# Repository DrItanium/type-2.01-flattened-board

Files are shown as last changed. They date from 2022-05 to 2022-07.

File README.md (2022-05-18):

This project is a flattening of my i960 Eurocard Bus design into a mini itx
motherboard. The idea is that by leveraging the mini-itx/atx ecosystem I will
save a bunch of money. In this design, the chipset is an adafruit grand central
m4 with ram being provided by a file on an SD card (dedicated SD channel +
an effective cache implementation works wonders to hide nearly all latency).

The grand central m4 is exposed out the io shield area. You will see the
evolution of many ideas and where it started from as well. 

I have two 4809 microcontrollers on board as well. They are titled ME and PIC. 

ME or Management Engine abstracts the details of how one handles memory
transactions made by the i960. It generates the 20MHz clock and runs in lock
step with the i960Sx as well. The chipset (GCM4) interacts with the ME to
satisfy these requests. The communication protocol between chipset and ME is
designed to allow the chipset to run completely independently of the ME without
running too fast or out of sync. The ME also uses its CCLs to reduce the number
of ICs required. This includes:

- Enabling data lines on request by chipset
- Fail signal detection (externally synchronized)
- Ready signal detection with external override
- Controlling the i960 reset line (Chipset, ME, and PIC all have to be ready
		before i960 is pulled out of reset). Pullups and an external inverter
		are used to make sure that the i960 will stay in reset until everything is
		ready. 

PIC or Programmable Interrupt Controller makes sure that one can invoke any of
the four exposed interrupt lines by the i960Sx in a consistent manner. A serial
communication channel is provided to allow the chipset to configure the PIC.
The general idea is that each CCL of the PIC is devoted to a separate interrupt
line. The first three interrupts (~INT0, INT1, INT2) are meant for dedicated
interrupts within the i960. The third interrupt (~INT3) is the lowest priority
and designed for the chipset. When the chipset needs to interrupt the i960, it
sends an ~INT3. This causes the i960 to query the chipset what kind of
interrupt it was (through MMIO) and then send an IAC message to trigger an
internal interrupt. 

The PIC has peripherals like timers and such that can be connected to the CCLs
to trigger interrupts. The chipset talks with the PIC through the serial
connection to setup these options via the event system.

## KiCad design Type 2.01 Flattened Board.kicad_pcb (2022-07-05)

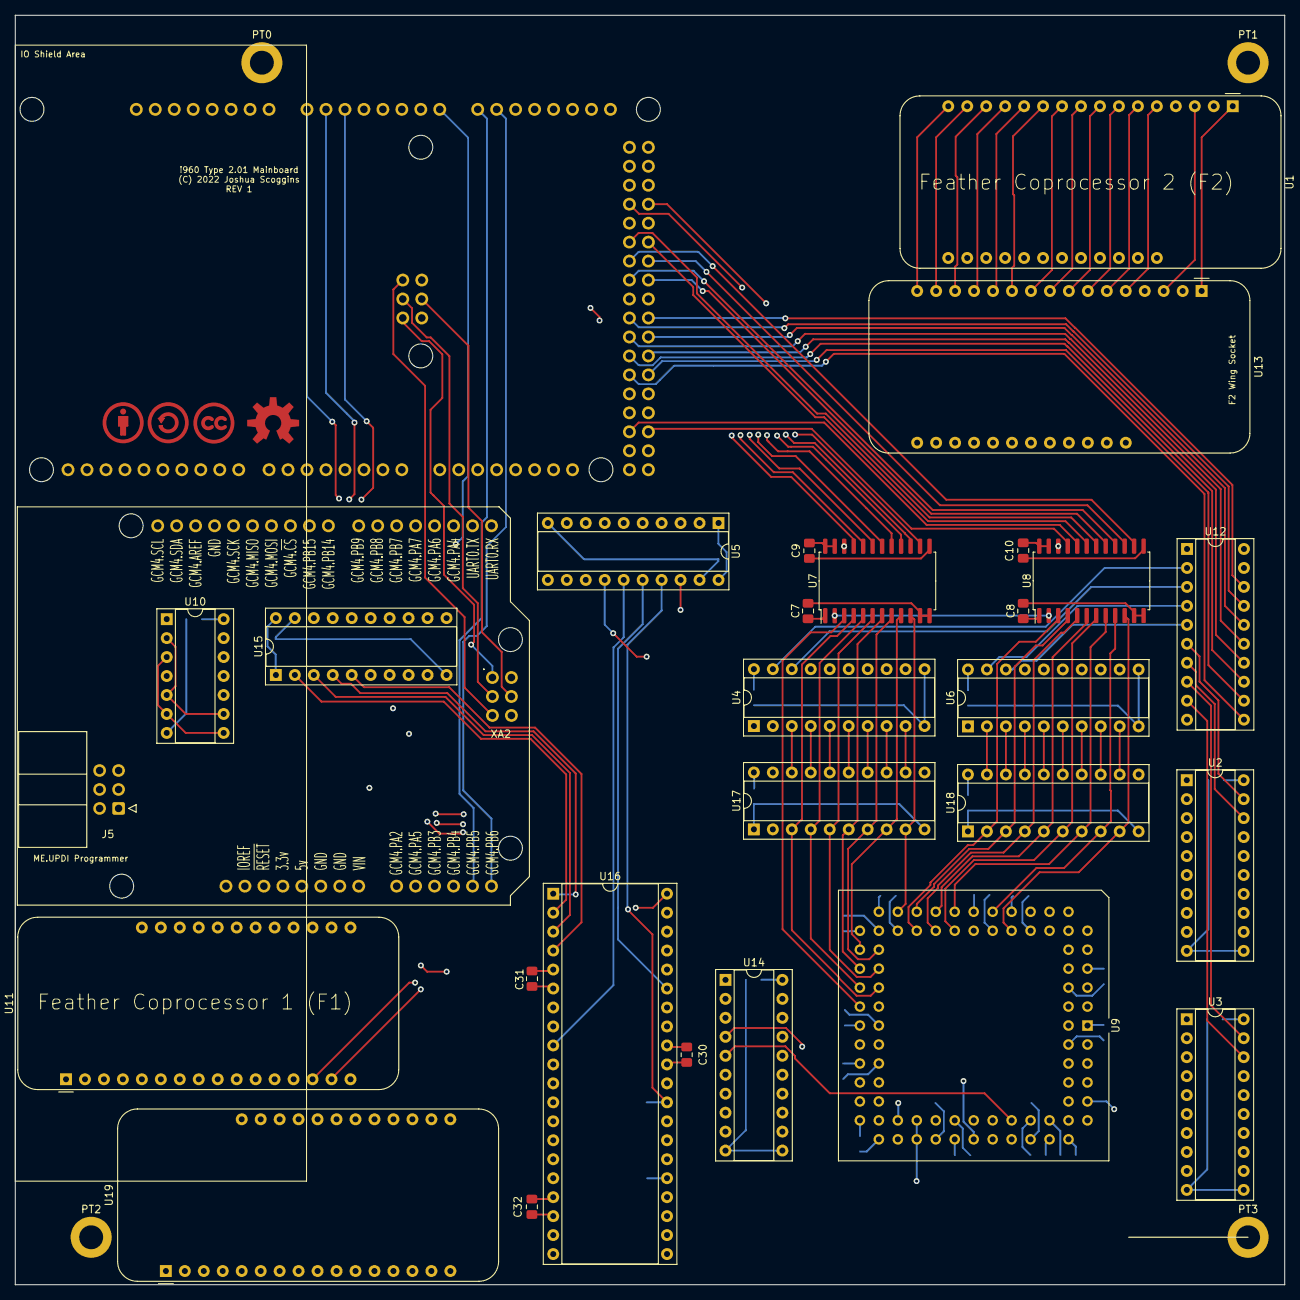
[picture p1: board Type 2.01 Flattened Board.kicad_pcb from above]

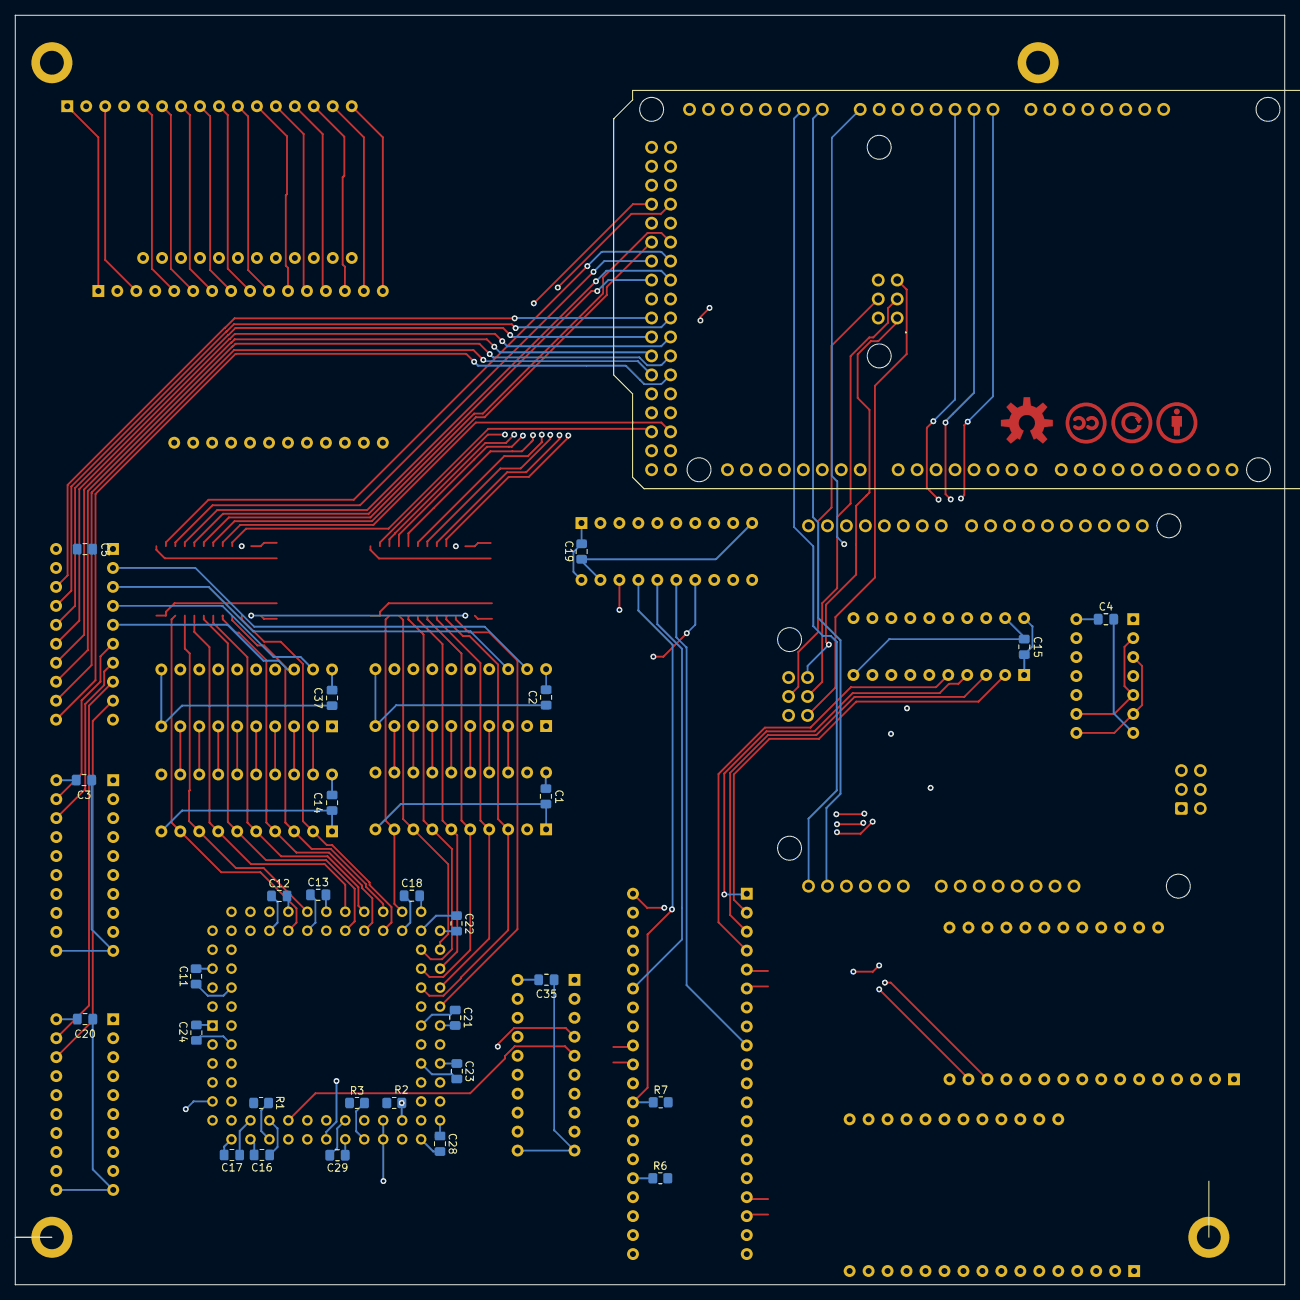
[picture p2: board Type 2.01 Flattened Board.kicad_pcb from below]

Board: 4 copper layers, 170.0 x 170.0 mm, 61 parts (29 on the bottom side), 209 nets.

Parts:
C1, C2, C3, C4, C5, C7, C8, C9, C10, C11, C12, C13, C14, C15, C16, C17, C18, C19, C20, C21, C22, C23, C24, C28, C29, C30, C31, C32, C35, C37: 0.1uF; C_0805_2012Metric_Pad1.18x1.45mm_HandSolder
J5: Conn_02x03_Odd_Even; IDC-Header_2x03_P2.54mm_Horizontal
PT0, PT1, PT2, PT3: MountingHole; MountingHole_3.2mm_M3_ISO14580_Pad
R1: 910; R_0805_2012Metric_Pad1.20x1.40mm_HandSolder
R2, R3, R6, R7: 10k; R_0805_2012Metric_Pad1.20x1.40mm_HandSolder
U1, U11, U13, U19: Adafruit_FeatherWing; Adafruit_Feather
U2, U3, U4, U6, U14: GAL16V8; DIP-20_W7.62mm_Socket
U5, U12, U15: 74AHC245; DIP-20_W7.62mm_Socket
U7, U8: 74LVC8T245; SOIC-24W_7.5x15.4mm_P1.27mm
U9: i960Sx_PLCC84; PLCC-84_THT-Socket
U10: 74AHC125; DIP-14_W7.62mm_Socket
U16: ATmega4809-PF; DIP-40_W15.24mm_Socket
U17, U18: 74AHC573; DIP-20_W7.62mm_Socket
XA1: Adafruit Grand Central M4; Arduino_Mega2560_Shield
XA2: Arduino_Uno_Shield

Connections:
+3.3V: U1.2 (3.3v), U1.28 (BAT), U11.2 (3.3v), U11.28 (BAT), U13.2 (3.3v), U13.28 (BAT), U19.2 (3.3v), U19.28 (BAT)
+3V3: XA1.3V3 (3.3V), XA2.3V3 (3.3V)
+5V: C1.1, C2.1, C3.1, C7.1, C8.1, C11.1, C12.1, C13.1, C14.1, C16.1, C17.1, C18.1, C19.1, C20.1, C21.1, C22.1, C23.1, C24.1, C28.1, C29.1, C30.1, C31.1, C32.1, C35.1, C37.1, J5.2, R1.2, R2.1, R3.1, R6.2, R7.2, U1.26 (USB), U2.20 (VCC), U3.20 (VCC), U4.20 (VCC), U5.1 (A->B), U5.20 (VCC), U6.20 (VCC), U7.1 (VCCA), U8.1 (VCCA), U9.1 (VCC), U9.6 (VCC), U9.17 (VCC), U9.21 (VCC), U9.31 (VCC), U9.33 (VCC), U9.44 (VCC), U9.47 (VCC), U9.53 (VCC), U9.62 (VCC), U9.71 (VCC), U9.73 (VCC), U11.26 (USB), U13.26 (USB), U14.20 (VCC), U16.5 (VCC), U16.17 (AVCC), U16.31 (VCC), U17.20 (VCC), U18.20 (VCC), U19.26 (USB), XA1.5V1 (5V), XA1.5V2 (SPI_5V), XA1.5V3 (5V), XA1.5V4 (5V), XA2.5V1 (5V), XA2.5V2 (SPI_5V)
/AREF: XA1.AREF, XA2.AREF
/BUS.PA2: XA1.A0, XA2.A0
/BUS.PA4: U1.10 (A5), U13.10 (A5), XA1.A13
/BUS.PA5: XA1.A1, XA2.A1
/BUS.PA6: U1.1 (~RESET), U13.1 (~RESET), XA1.A14
/BUS.PB2: U10.4, XA1.D9, XA2.D9
/BUS.PB3: XA1.A2, XA2.A2
/BUS.PB4: XA1.A7, XA2.A3
/BUS.PB5: XA1.A8, XA2.A4
/BUS.PB6: XA1.A9, XA2.A5
/BUS.PB7: U11.1 (~RESET), U19.1 (~RESET), XA1.A10
/BUS.PB8: U1.15 (TX), U13.15 (TX), XA1.A11
/BUS.PB9: U1.14 (RX), U13.14 (RX), XA1.A12
/BUS.PB18: U10.10, XA1.D8, XA2.D8
/BUS.PC18: XA1.D2 (D2_INT0), XA2.D2 (D2_INT0)
/BUS.PC19: XA1.D3 (D3_INT1), XA2.D3 (D3_INT1)
/BUS.PC20: XA1.D4, XA2.D4
/BUS.PC21: XA1.D5, XA2.D5
/BUS.PD20: XA1.D6, XA2.D6
/BUS.PD21: XA1.D7, XA2.D7
/DAZZLER.MISO: U10.2, U10.5, U10.9, XA2.D12
/Feather Copro0/Feather.A0: U11.5 (A0), U19.5 (A0)
/Feather Copro0/Feather.A1: U11.6 (A1), U19.6 (A1)
/Feather Copro0/Feather.A2: U11.7 (A2), U19.7 (A2)
/Feather Copro0/Feather.A3: U11.8 (A3), U19.8 (A3)
/Feather Copro0/Feather.A4: U11.9 (A4), U19.9 (A4)
/Feather Copro0/Feather.AREF: U11.3 (AREF), U19.3 (AREF)
/Feather Copro0/Feather.D5: U11.19 (D5), U19.19 (D5)
/Feather Copro0/Feather.D6: U11.20 (D6), U19.20 (D6)
/Feather Copro0/Feather.D9: U11.21 (D9), U19.21 (D9)
/Feather Copro0/Feather.D10: U11.22 (D10), U19.22 (D10)
/Feather Copro0/Feather.D11: U11.23 (D11), U19.23 (D11)
/Feather Copro0/Feather.D12: U11.24 (D12), U19.24 (D12)
/Feather Copro0/Feather.D13: U11.25 (D13), U19.25 (D13)
/Feather Copro0/Feather.EN: U11.27 (EN), U19.27 (EN)
/Feather Copro0/Feather.FREE: U11.16 (*), U19.16 (*)
/Feather Copro0/Feather.MISO: U11.13 (MISO), U19.13 (MISO)
/Feather Copro0/Feather.MOSI: U11.12 (MOSI), U19.12 (MOSI)
/Feather Copro0/Feather.SCK: U11.11 (SCK), U19.11 (SCK)
/Feather Copro0/Feather.SCL: U11.18 (SCL), U19.18 (SCL)
/Feather Copro0/Feather.SDA: U11.17 (SDA), U19.17 (SDA)
/Feather Copro1/Feather.A0: U1.5 (A0), U13.5 (A0)
/Feather Copro1/Feather.A1: U1.6 (A1), U13.6 (A1)
/Feather Copro1/Feather.A2: U1.7 (A2), U13.7 (A2)
/Feather Copro1/Feather.A3: U1.8 (A3), U13.8 (A3)
/Feather Copro1/Feather.A4: U1.9 (A4), U13.9 (A4)
/Feather Copro1/Feather.AREF: U1.3 (AREF), U13.3 (AREF)
/Feather Copro1/Feather.D5: U1.19 (D5), U13.19 (D5)
/Feather Copro1/Feather.D6: U1.20 (D6), U13.20 (D6)
/Feather Copro1/Feather.D9: U1.21 (D9), U13.21 (D9)
/Feather Copro1/Feather.D10: U1.22 (D10), U13.22 (D10)
/Feather Copro1/Feather.D11: U1.23 (D11), U13.23 (D11)
/Feather Copro1/Feather.D12: U1.24 (D12), U13.24 (D12)
/Feather Copro1/Feather.D13: U1.25 (D13), U13.25 (D13)
/Feather Copro1/Feather.EN: U1.27 (EN), U13.27 (EN)
/Feather Copro1/Feather.FREE: U1.16 (*), U13.16 (*)
/Feather Copro1/Feather.MISO: U1.13 (MISO), U13.13 (MISO)
/Feather Copro1/Feather.MOSI: U1.12 (MOSI), U13.12 (MOSI)
/Feather Copro1/Feather.SCK: U1.11 (SCK), U13.11 (SCK)
/Feather Copro1/Feather.SCL: U1.18 (SCL), U13.18 (SCL)
/Feather Copro1/Feather.SDA: U1.17 (SDA), U13.17 (SDA)
/GCM4.A0: U5.7 (A5), XA1.D39
/GCM4.A1: U5.8 (A6), XA1.D38
/GCM4.D0: U7.21 (B1), XA1.A3
/GCM4.D1: U7.20 (B2), XA1.A4
/GCM4.D2: U7.19 (B3), XA1.A5
/GCM4.D3: U7.18 (B4), XA1.A6
/GCM4.D4: U7.17 (B5), XA1.D48
/GCM4.D5: U7.16 (B6), XA1.D49
/GCM4.D6: U7.15 (B7), XA1.D46
/GCM4.D7: U7.14 (B8), XA1.D47
/GCM4.D8: U8.21 (B1), XA1.D25
/GCM4.D9: U8.20 (B2), XA1.D24
/GCM4.D10: U8.19 (B3), XA1.D45
/GCM4.D11: U8.18 (B4), XA1.D44
/GCM4.D12: U8.17 (B5), XA1.D41
/GCM4.D13: U8.16 (B6), XA1.D40
/GCM4.D14: U8.15 (B7), XA1.D43
/GCM4.D15: U8.14 (B8), XA1.D42
/GCM4.HLDA: U15.14 (B4), XA1.D17 (D17_RX2)
/GCM4.HOLD: U5.6 (A4), XA1.D26
/GCM4.L0: U12.18 (B0), XA1.D37
/GCM4.L1: U12.17 (B1), XA1.D36
/GCM4.L2: U12.16 (B2), XA1.D35
/GCM4.L3: U12.15 (B3), XA1.D34
/GCM4.L4: U12.14 (B4), XA1.D33
/GCM4.L5: U12.13 (B5), XA1.D32
/GCM4.L6: U12.12 (B6), XA1.D31
/GCM4.L7: U12.11 (B7), XA1.D30
/GCM4.~BE0: U15.13 (B5), XA1.D18 (D18_TX1)
/GCM4.~BE1: U15.12 (B6), XA1.D19 (D19_RX1)
/GCM4.~BOOT_SUCCESSFUL: U15.15 (B3), XA1.D16 (D16_TX2)
/GCM4.~BURST_LAST: U15.16 (B2), XA1.D10
/GCM4.~CHIPSET_BOOTED: U5.2 (A0), XA1.D29
/GCM4.~DO_CYCLE: U15.17 (B1), XA1.D11
/GCM4.~FEATHER_INT0: U11.10 (A5), U19.10 (A5), XA1.D13
/GCM4.~INTR0: U5.5 (A3), XA1.D22
/GCM4.~IN_TRANSACTION: U15.18 (B0), XA1.D12
/GCM4.~READY: U5.4 (A2), XA1.D23
/GCM4.~RESET960: U5.3 (A1), XA1.D27
/MISO: U10.3, U10.6, U10.8, XA1.D50
/MOSI: XA1.D51, XA2.D11
/SCK: XA1.D52, XA2.D13
/SCL: XA1.SCL, XA2.SCL
/SDA: XA1.SDA, XA2.SDA
/SPI_MISO: XA1.MISO (SPI_MISO), XA2.MISO (SPI_MISO)
/SPI_MOSI: XA1.MOSI (SPI_MOSI), XA2.MOSI (SPI_MOSI)
/SPI_SCK: XA1.SCK (SPI_SCK), XA2.SCK (SPI_SCK)
/UART0.RX: XA1.D0 (D0_RX0), XA2.D0 (D0_RX0)
/UART0.TX: XA1.D1 (D1_TX0), XA2.D1 (D1_TX0)
/UART3.RX: U11.15 (TX), U19.15 (TX), XA1.D15 (D15_RX3)
/UART3.TX: U11.14 (RX), U19.14 (RX), XA1.D14 (D14_TX3)
/VIN: XA1.VIN, XA2.VIN
/i960.A1: U4.3 (I3), U17.18 (Q1)
/i960.A2: U4.4 (I4), U17.17 (Q2)
/i960.A3: U4.5 (I5), U17.16 (Q3)
/i960.A4: U4.6 (I6), U17.15 (Q4)
/i960.A5: U4.7 (I7), U17.14 (Q5)
/i960.A6: U4.8 (I8), U17.13 (Q6)
/i960.A7: U4.9 (I9), U17.12 (Q7)
/i960.A8: U6.2 (I2), U18.19 (Q0)
/i960.A9: U6.3 (I3), U18.18 (Q1)
/i960.A10: U6.4 (I4), U18.17 (Q2)
/i960.A11: U6.5 (I5), U18.16 (Q3)
/i960.A12: U6.6 (I6), U18.15 (Q4)
/i960.A13: U6.7 (I7), U18.14 (Q5)
/i960.A14: U6.8 (I8), U18.13 (Q6)
/i960.A15: U6.9 (I9), U18.12 (Q7)
/i960.A16: U2.2 (I2), U9.16 (A16)
/i960.A17: U2.3 (I3), U9.15 (A17)
/i960.A18: U2.4 (I4), U9.14 (A18)
/i960.A19: U2.5 (I5), U9.13 (A19)
/i960.A20: U2.6 (I6), U9.12 (A20)
/i960.A21: U2.7 (I7), U9.11 (A21)
/i960.A22: U2.8 (I8), U9.10 (A22)
/i960.A23: U2.9 (I9), U9.9 (A23)
/i960.A24: U3.2 (I2), U9.8 (A24)
/i960.A25: U3.3 (I3), U9.5 (A25)
/i960.A26: U3.4 (I4), U9.4 (A26)
/i960.A27: U3.5 (I5), U9.3 (A27)
/i960.A28: U3.6 (I6), U9.83 (A28)
/i960.A29: U3.7 (I7), U9.82 (A29)
/i960.A30: U3.8 (I8), U9.81 (A30)
/i960.A31: U3.9 (I9), U9.80 (A31)
/i960.CLK: U14.1 (I1/CLK), U16.36 ((XDIR0/SCL/CCL0-OUT)PA3)
/i960.CLK2: U9.55 (CLK2), U16.40 ((XDIR0_ALT/CLKO/~SS)PA7)
/i960.D0: U7.3 (A1), U9.41 (D0)
/i960.D1: U7.4 (A2), U9.40 (AD1), U17.3 (D1)
/i960.D2: U7.5 (A3), U9.39 (AD2), U17.4 (D2)
/i960.D3: U7.6 (A4), U9.38 (AD3), U17.5 (D3)
/i960.D4: U7.7 (A5), U9.37 (AD4), U17.6 (D4)
/i960.D5: U7.8 (A6), U9.36 (AD5), U17.7 (D5)
/i960.D6: U7.9 (A7), U9.35 (AD6), U17.8 (D6)
/i960.D7: U7.10 (A8), U9.30 (AD7), U17.9 (D7)
/i960.D8: U8.3 (A1), U9.29 (AD8), U18.2 (D0)
/i960.D9: U8.4 (A2), U9.28 (AD9), U18.3 (D1)
/i960.D10: U8.5 (A3), U9.27 (AD10), U18.4 (D2)
/i960.D11: U8.6 (A4), U9.26 (AD11), U18.5 (D3)
/i960.D12: U8.7 (A5), U9.25 (AD12), U18.6 (D4)
/i960.D13: U8.8 (A6), U9.24 (AD13), U18.7 (D5)
/i960.D14: U8.9 (A7), U9.20 (AD14), U18.8 (D6)
/i960.D15: U8.10 (A8), U9.19 (AD15), U18.9 (D7)
/i960.DT\~R: U7.2 (DIR), U8.2 (DIR), U9.68 (DT\~R)
/i960.W\~R: U4.2 (I2), U9.66 (W\~R)
/i960.~BE0: U9.52 (~BE0), U14.3 (I3), U15.7 (A5)
/i960.~BE1: U9.51 (~BE1), U14.4 (I4), U15.8 (A6)
/i960.~DEN: U7.22 (~OE), U8.22 (~OE), U9.67 (~DEN), U16.28 ((AIN15)PF5)
/i960/5V_~CHIPSET_BOOTED: U5.18 (B0), U16.34 ((RXD0/CCL0-IN1)PA1)
/i960/5V_~READY: U5.16 (B2), U16.35 ((XCK0/SDA/CCL0-IN2)PA2)
/i960/5V_~RESET: R7.1, U5.17 (B1), U16.29 (PF6(~RESET))
/i960/ALE: U9.78 (ALE), U17.11 (Load), U18.11 (Load)
/i960/C0: U4.19 (IO1), U12.2 (A0)
/i960/C1: U4.18 (IO2), U12.3 (A1)
/i960/C2: U6.19 (IO1), U12.4 (A2)
/i960/C3: U6.18 (IO2), U12.5 (A3)
/i960/C4: U2.19 (IO1), U12.6 (A4)
/i960/C5: U2.18 (IO2), U12.7 (A5)
/i960/C6: U3.19 (IO1), U12.8 (A6)
/i960/C7: U3.18 (IO2), U12.9 (A7)
/i960/INT0_OUT: U14.2 (I2), U16.12 ((AIN3/CCL2-OUT)PD3)
/i960/READY_INTERMEDIATE: U14.6 (I6), U16.26 ((AIN13/XDIR2/CCL3-OUT)PF3)
/i960/SEL_A0: U2.12 (IO8), U3.12 (IO8), U4.12 (IO8), U5.13 (B5), U6.12 (IO8)
/i960/SEL_A1: U2.13 (IO7), U3.13 (IO7), U4.13 (IO7), U5.12 (B6), U6.13 (IO7)
/i960/UPDI: J5.1, U16.30 (UPDI)
/i960/UPDI_RXD: J5.4, U16.8 ((RXD1_ALT)PC5)
/i960/UPDI_TXD: J5.5, U16.7 ((TXD1_ALT)PC4)
/i960/i960.HLDA: U9.61 (HLDA), U15.6 (A4)
/i960/i960.HOLD: U5.14 (B4), U9.64 (HOLD)
/i960/i960.~BLAST: U9.69 (~BLAST\~FAIL), U14.5 (I5), U16.27 ((AIN14)PF4)
/i960/i960.~BOOT_SUCCESSFUL: U15.5 (A3), U16.4 ((XDIR1/~SS_ALT/CCL1-OUT)PC3)
/i960/i960.~BURST_LAST: U15.4 (A2), U16.1 ((TXD1/MOSI_ALT/CCL1-IN0)PC0)
/i960/i960.~DO_CYCLE: U15.3 (A1), U16.3 ((XCK1/SCK_ALT/CCL1-IN2)PC2)
/i960/i960.~INT0: R2.2, U9.57 (~INT0), U14.19 (IO1)
/i960/i960.~INT3: R3.2, U9.60 (~INT3)
/i960/i960.~IN_TRANSACTION: U15.2 (A0), U16.2 ((RXD1/MISO_ALT/CCL1-IN1)PC1)
/i960/i960.~LOCK: R1.1, U9.70 (~LOCK)
/i960/~CHIPSET_INT: U5.15 (B3), U16.9 ((AIN0/CCL2-IN0)PD0)
/i960/~ME_FAIL_IN: U14.18 (IO2), U16.33 ((CLKI/TXD0/CCL0-IN0)PA0)
/i960/~READY960: U9.79 (~READY), U14.17 (I03)
/i960/~RESET960: U9.56 (~RESET), U14.16 (IO4)
/i960/~RESET_INTERMEDIATE: R6.1, U14.7 (I7), U16.25 ((AIN12/XCK2/CCL3-IN2)PF2)
/~CS: U10.1, XA1.D53 (D53_SS), XA2.D10 (D10_CS)
/~RESET_{0}: XA1.RST1 (RESET), XA2.RST1 (RESET)
/~RESET_{1}: XA1.RST2 (SPI_RESET), XA2.RST2 (SPI_RESET)
GND: C1.2, C2.2, C3.2, C4.2, C5.2, C7.2, C8.2, C9.2, C10.2, C11.2, C12.2, C13.2, C14.2, C15.2, C16.2, C17.2, C18.2, C19.2, C20.2, C21.2, C22.2, C23.2, C24.2, C28.2, C29.2, C30.2, C31.2, C32.2, C35.2, C37.2, J5.6, U1.4 (GND), U2.10 (GND), U2.11 (I10/~OE), U3.10 (GND), U3.11 (I10/~OE), U4.10 (GND), U4.11 (I10/~OE), U5.10 (GND), U5.19 (CE), U6.10 (GND), U6.11 (I10/~OE), U7.11 (GND), U7.12 (GND), U7.13 (GND), U8.11 (GND), U8.12 (GND), U8.13 (GND), U9.7 (GND), U9.18 (GND), U9.22 (GND), U9.32 (GND), U9.34 (GND), U9.43 (GND), U9.48 (GND), U9.54 (GND), U9.58 (INT1), U9.59 (INT2), U9.63 (GND), U9.72 (GND), U9.74 (GND), U9.77 (GND), U9.84 (GND), U10.7 (GND), U11.4 (GND), U12.10 (GND), U12.19 (CE), U13.4 (GND), U14.10 (GND), U14.11 (I10/~OE), U15.10 (GND), U15.19 (CE), U16.6 (GND), U16.18 (GND), U16.32 (GND), U17.1 (OE), U17.10 (GND), U18.1 (OE), U18.10 (GND), U19.4 (GND), XA1.GND1 (GND), XA1.GND2 (GND), XA1.GND3 (GND), XA1.GND4 (SPI_GND), XA1.GND5 (GND), XA1.GND6 (GND), XA2.GND1 (GND), XA2.GND2 (GND), XA2.GND3 (GND), XA2.GND4 (SPI_GND)
VCCB: C4.1, C5.1, C9.1, C10.1, C15.1, U7.23 (VCCB), U7.24 (VCCB), U8.23 (VCCB), U8.24 (VCCB), U10.14 (VCC), U12.1 (A->B), U12.20 (VCC), U15.1 (A->B), U15.20 (VCC), XA1.IORF (IOREF), XA2.IORF (IOREF)

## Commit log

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2022-05-12 Added arduino uno shield port
    Idea is to try and use the arduino uno pin numbers to make library usage
    that much easier!
    [Type 2.01 Flattened Board.kicad_sch]
2022-05-12 Fix up analog pinout so that reading and writing data lines is as efficient as possible
    It does require using some of the analog pins that would be found in the
    uno section. Just use some of the other analog pins found in the
    extended set instead.
    [Type 2.01 Flattened Board.kicad_sch]
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2022-05-13 Start defining the mux input and drop the uno connector for now
    I need a working board first
    [MuxInput.kicad_sch, SingleAHC158.kicad_sch, Type 2.01 Flattened Board.kicad_sch]
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2022-05-13 Update everything and keep laying out the i960 features
    Use bus wires as much as possible
    [8Selection.kicad_sch, MuxInput.kicad_sch, SingleAHC158.kicad_sch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]
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2022-05-13 Put the management engine into the i960 sheet
    It will be responsible for generating the 20mhz clock. However, the
    interrupts probably need to be handled externally by another processor
    to make sure we don't bog down the management engine.
    [Type 2.01 Flattened Board.kicad_sch, i960.kicad_sch]
2022-05-13 USE HC158/AHC158s to allow me to change the aux hardware on this board
    The issue I'm seeing is that this board is very complex and I need a way
    to fix bugs without adding a lot of strange garbage. My plan is to move
    the management engine and various parts onto a board that is plugged
    into the main board. The other way I could do it is provide this
    capability but use multiplexer chips to select the source. That way it
    can work without this. Plus I can still fix bugs in the future.
    Because of this, the management engine will be responsible for:
    - Clock Generation
    -- 10MHz is generated externally to save on CCLs
    - Ready signal synchronization
    -- This is one of the features that will be overlo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
    [Type 2.01 Flattened Board.kicad_sch, i960.kicad_sch]
2022-05-13 Fix up the fail synchronization circuit
    [i960.kicad_sch]
2022-05-14 Use AHC244s instead of AHC158s for the address lines
    Makes it much easier to design the selection bus!
    [MuxInput.kicad_sch, Type 2.01 Flattened Board.kicad_sch, i960.kicad_sch]
2022-05-14 Start defining the components needed for keeping track of the address and data lines
    [8BitBidirectionalPort.kicad_sch, Type 2.01 Flattened Board.kicad_sch, i960DataTranceivers.kicad_sch]
2022-05-14 Added a 16-bit transceiver to data lines
    There is no latch in this design, the GCM4 is responsible for keeping
    the lines active when handling read requests from the i960. This isn't
    that big of a deal. It just means that we have to keep the data line id
    set for as long as possible.
    This is basically what I do now for the gcm4 based boards just without
    the address bits set. The data lines stay set until the next time they
    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
    [8BitBidirectionalPort.kicad_sch, Type 2.01 Flattened Board.kicad_sch, i960DataTranceivers.kicad_sch]
2022-05-14 Instead of using a double buffer design, just connect the bus selector and DEN lines together with an or gate.
    That way we keep the transceivers off of the bus.
    [Type 2.01 Flattened Board.kicad_sch, i960DataTranceivers.kicad_sch]
2022-05-14 Use an AHC138/HC138 for decoding the fail circuit
    It is much simpler this way. I can also use the other states to define
    the actions to perform.
    [MuxInput.kicad_sch, Type 2.01 Flattened Board.kicad_sch, i960.kicad_sch]
2022-05-14 Make the management engine responsible for handling reset capabilities
    My idea is to use the event system to route the ME_Booted pin to a ccl
    within the me to complete the package.
    The output of this ccl will be RESET960 and that can be handled manually
    until we get the CCLs up. Then we can wait until all the parts have
    started up. Hell we can use an AHC138 for this as well!
    [i960.kicad_sch]
2022-05-14 Reset circuit handled by an AHC138
    [Type 2.01 Flattened Board.kicad_sch, i960.kicad_sch]
2022-05-14 Use the Management Engine for the reset controller.
    It becomes much easier to work around logic bugs with the CCL. I just
    setup PF0 as an output but wire that to CCL3.EVTA (I do this for the
    10MHz signal tests where I routed PA7 as a event source)
    So that allows me to control the CCL that way. If that fails then I can
    just do polling on boot with no problems.
    I also added pullups to make sure that on a reset from the chipset we
    will keep the i960 in reset.
    [Type 2.01 Flattened Board.kicad_sch, i960.kicad_sch]
2022-05-14 Integrate the 10MHz signal generator into the Management Engine
    Makes it much easier to control things
    [Type 2.01 Flattened Board.kicad_sch, i960.kicad_sch]
2022-05-14 Put the external ready hardware on a breakout connector
    If I run into problems or bugs, we can connect a small handler board
    onto the header and override the issue really quickly. If you don't plug
    in the connector then no problem we will detect that.
    I have it routed through the CCL in a very trivial manner. The nice
    thing is that regardless of where we do the ready signal computation we
    will always use CCL2.IN0 for ~{ME_READY}
    [Type 2.01 Flattened Board.kicad_sch, i960.kicad_sch]
2022-05-14 Fix a screwup for labels
    [i960.kicad_sch]
2022-05-14 Use an AHC174 to handle teh fail sync
    I realized that we can just pass the sync'd result without doing an
    invert at all. It means that I can easily resolve the logic in the
    management engine without shenanigans!
    I am also thinking that it provides a better ready signal sync backup
    than the external device. I can just reroute it easily
    [Type 2.01 Flattened Board.kicad_sch, i960.kicad_sch]
2022-05-14 Just connect HOLD directly to the i960 through an inverter from GCM4
    No need for extra logic because the hold will handle that
    [Type 2.01 Flattened Board.kicad_sch, i960.kicad_sch]
2022-05-14 Use an inverter and and-gate combo with the hex flip flop
    [Type 2.01 Flattened Board.kicad_sch, i960.kicad_sch]
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2022-05-15 Initial layout but I think I can use AHC157s to assist in device selection
    [Type 2.01 Flattened Board.kicad_pcb, Type 2.01 Flattened Board.kicad_sch, i960.kicad_sch]
2022-05-15 use the output enable lines on the latches and buffers to do direct logic level conversion
    Save some chips in the process.
    [MuxInput.kicad_sch, Register16_4.kicad_sch, Type 2.01 Flattened Board.kicad_sch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]
2022-05-15 Do a bulk update and fix all values
    [Type 2.01 Flattened Board.kicad_sch, i960DataTranceivers.kicad_sch]
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2022-05-15 Connect LOCK and AS to the management engine
    Don't do a breakout!
    [Type 2.01 Flattened Board.kicad_pcb, Type 2.01 Flattened Board.kicad_sch, i960.kicad_sch]
2022-05-15 Use a third 4809 running independently to act as glue and startup unit.
    I was able to remove a nor gate ic by adding. I am also planning to use
    the CCLs for other features as well. Perhaps as a simpler inverter.
    [Register16_4.kicad_sch, Type 2.01 Flattened Board.kicad_pcb, Type 2.01 Flattened Board.kicad_sch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]
2022-05-15 Use glue to do the fail circuit.
    Eliminates an AHC74 from the board!!!
    Technically, it also could remove the AHC138 from the board as well. I
    think I will do that too. I will instead use the AHC139 to also decode
    that as well.
    [Type 2.01 Flattened Board.kicad_pcb, Type 2.01 Flattened Board.kicad_sch, i960.kicad_sch]
2022-05-15 Added a communication channel between the different glue chips.
    I am considering connecting this up to the chipset through glue
    [Register16_4.kicad_sch, Type 2.01 Flattened Board.kicad_pcb, Type 2.01 Flattened Board.kicad_sch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]
2022-05-15 Use GLUE to setup a query network. I want to make sure that we can talk to the different chips as easily as possible.
    [i960.kicad_sch]
2022-05-16 Did the research with using an external 20 MHz signal.
    It is neat but generating a 10mhz clock is far less flexible with the
    gcm4 compared to the 4809. However, I decided to add a 74AHC74 to the
    board and route it into the ME to eliminate GLUE.
    [Type 2.01 Flattened Board.kicad_sch, i960.kicad_sch]
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2022-05-16 Drop the communication channel to both 4809s.
    There is no point in doing it and besides these chips should be
    operating independently of anything else. If I wanted to configure the
    PIC then it should be through the numerous free GPIOs I have access to
    on the PIC itself. I count at least 13 pins free. I could even add an io
    expander to control these aspects as well. I may also have the PIC run
    off of its own 20MHz oscillator to free up a pin. The CLK1 signal is the
    most important part anyways.
    [i960.kicad_sch]
2022-05-16 Make sure we can mask interrupts externally and also make the serial connections to each device a separate thing.
    [i960.kicad_sch]
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2022-05-16 layout troubles
    I think I need to step back and simplify things.
    Having the uno connector on board doesn't actually make that much sense
    to be honest. I'm going to drop it out
    [Type 2.01 Flattened Board.kicad_pcb]
2022-05-16 Drop the uno connector
    It doesn't make much sense. Those pins should be exposed externally
    instead.
    [Type 2.01 Flattened Board.kicad_sch]
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2022-05-19 Chipset only gets access to ~INT3 by default
    Use the other interrupts for peripherals on the PIC.
    [Type 2.01 Flattened Board.kicad_sch, i960.kicad_sch]
2022-05-19 Save an AHC245 by reducing the number of interrupts accessible by the chipset
    [Type 2.01 Flattened Board.kicad_sch, i960.kicad_sch]
2022-05-19 Drop the external connector for overriding.
    I think I'm just going to add the two synchronizers as a backup but put
    the edge detection logic into the CCL as the backup
    [Type 2.01 Flattened Board.kicad_sch, i960.kicad_sch]
2022-05-19 Put the falling edge detector flip-flops on the main board.
    It will be connected to IN1 and IN2 of CCL2. I am going to add a jumper
    block to allow this extra flip flop block to be activated
    [Type 2.01 Flattened Board.kicad_sch, i960.kicad_sch]
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2022-05-19 Added a second inverter ic to allow HOLD and HLDA to be active low
    [Type 2.01 Flattened Board.kicad_sch, i960.kicad_sch]
2022-05-19 Use an AHC157 for the deactivation of the interrupt lines while changes are being made to the CCLs
    Instead of using tons of pullups and downs, use the AHC157 channel
    feature. Channel 0 is the connection between CCLS and i960. Channel 1 is
    a fixed pattern that is useful for booting and deactivating all
    interrupts
    [Register16_4.kicad_sch, Type 2.01 Flattened Board.kicad_sch, i960.kicad_sch]
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2022-05-19 Fix legit warnings and do more part selection
    [Type 2.01 Flattened Board.kicad_sch, i960.kicad_sch]
2022-05-19 Update the AHC138 to have the following pattern:
    High bits to Low bits
    Bit 2) W/~{R}
    Bit 1) ~{BE0}
    Bit 0) ~{BE1}
    The byte enable bits are reversed to make the output easier brain out
    since they are active low.
    [Register16_4.kicad_sch]
2022-05-19 Use an AHC245 instead of the 138
    We cannot have the hc138 directly connected because it won't be
    tristated. Instead use an AHC245 to tristate Register three upper and
    expose a pin header that allows the unused 10 pins to be tied into the
    chipset regardless of voltage.
    [Register16_4.kicad_sch, Type 2.01 Flattened Board.kicad_sch, i960.kicad_sch]
2022-05-19 Added extra resistor pack for missing pullup part
    [Register16_4.kicad_sch, Type 2.01 Flattened Board.kicad_sch, i960.kicad_sch]
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2022-05-21 Replace the AHC245s with four AHC157s to simplify the design
    [8 bit to 4 bit mux.kicad_sch, SixteenBitTo8BitSelector.kicad_sch, Type 2.01 Flattened Board.kicad_sch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]
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2022-05-23 Fix grouping
    [Type 2.01 Flattened Board.kicad_pcb]
2022-05-23 Drop the 74AHC174 because the edge detector is fine.
    Also don't use a CCL for the reset detection. Instead, the two CCLs are
    way more useful for generating the 10mhz signal cleanly.
    I also am going do the reset circuit manually because it makes way more
    sense that way. I am even going to use the builtin pullups as well!
    I can also get rid of the ME_BOOTED pin. Still need to do that
    [Type 2.01 Flattened Board.kicad_pcb, Type 2.01 Flattened Board.kicad_sch, i960.kicad_sch]
2022-05-23 Get rid of ME_BOOTED because it is no longer necessary with the reset circuit no longer handled by a CCL.
    Turns out to be a massive waste that way otherwise.
    [Type 2.01 Flattened Board.kicad_sch, i960.kicad_sch]
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2022-05-24 Correct the feather symbol and breakouts
    Also fix the VCC pin being bound to +5V for some reason. Use VCCIO
    instead
    [Type 2.01 Flattened Board.kicad_pcb, Type 2.01 Flattened Board.kicad_sch, i960.kicad_sch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]
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2022-05-25 More layout fixes and bug fixes
    [Type 2.01 Flattened Board.kicad_pcb, Type 2.01 Flattened Board.kicad_sch, i960.kicad_sch]
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2022-06-20 Fix naming + more features
    [Type 2.01 Flattened Board.kicad_sch, i960.kicad_sch, i960DataTranceivers.kicad_sch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]
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2022-07-04 Adding a 16-to-8 muxer
    Realized that if I use two layers of AHC158s then it will handle
    inverting for me :)!
    [16to8Mux.kicad_sch, Type 2.01 Flattened Board.kicad_sch, i960.kicad_sch]
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2022-07-04 Drop the PIC and only have one interrupt line
    Move the FAIL circuit to the GAL as I have a working implementation for
    that as well!
    [Type 2.01 Flattened Board.kicad_sch, i960.kicad_sch]
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2022-07-04 Even more simplification and be able to reset feathers separately from the chipset
    Makes it possible to also reset them if needed as well
    [16to8Mux.kicad_sch, FeatherCoprocessor.kicad_sch, Type 2.01 Flattened Board.kicad_pcb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]
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2022-07-05 Fix up an issue with 3.3v vs 3v3 power planes
    Also, link up more power pads to corresponding power plane
    [FeatherCoprocessor.kicad_sch, Type 2.01 Flattened Board.kicad_sch]
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2022-07-09 Split connectors in half and place effectively on the board.
    Also make sure that we route everything correctly
    [FeatherCoprocessor.kicad_sch, Type 2.01 Flattened Board.kicad_sch, i960.kicad_sch]

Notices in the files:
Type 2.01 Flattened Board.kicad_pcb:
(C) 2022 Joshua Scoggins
